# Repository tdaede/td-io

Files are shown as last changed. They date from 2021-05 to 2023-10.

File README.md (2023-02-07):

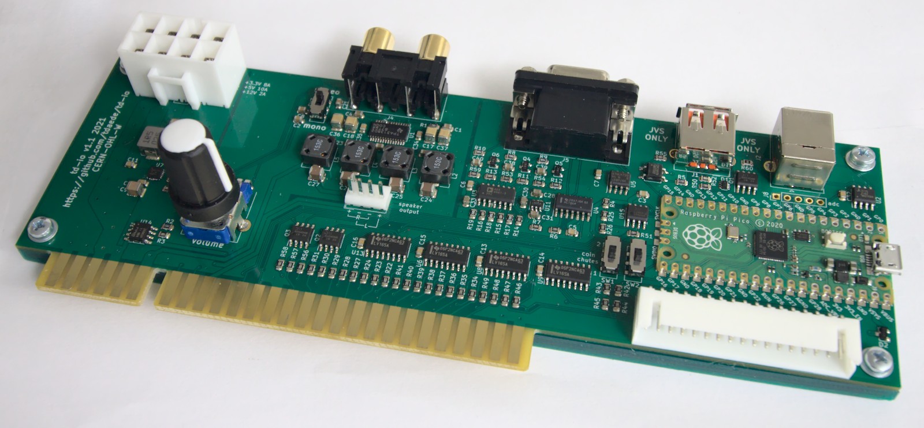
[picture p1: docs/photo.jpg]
td-io


td-io is a JVS I/O board designed to adapt older JAMMA-compatible cabinets to the newer JVS standard, used by modern arcade hardware such as the Naomi and exA. It features a number of independent systems to translate signals, drive cabinet hardware, and power JVS games.

# Features at a glance

* Chainable JVS I/O implementing a 2L12B panel and coin inputs
* JVS to JAMMA video converter compatible with all monitors
* Mono/stereo audio amplifier for driving JAMMA speakers
* JVS power connector providing 3.3V via an on-board converter
* High reliability, low heat generation and all solid state caps
* Upgradeable firmware

# Comparison with other JVS I/O options

| | TD-IO | Capcom I/O | Sega 838 | Exa I/O |
| --- | --- | --- | --- | --- |
| Lag (frames)  | 0 | 1 | 0 | 0 |
| Chaining | ✔ | ❌ | ✔ | ✔ |
| Video | ✔ | ✔ | ✔ | ❌ |
| Audio amp | ✔ | ✔ | ❌ | ❌ |
| 3.3V power | ✔ | ✔ | ❌ | ❌ |
| Amplified stereo | ✔ | ❌ | ❌ | ❌ |

# JVS inputs

The JVS I/O bus connects to the board via USB-style A and B connectors. Daisy chaining is supported. The I/O presents two players, each with a single joystick/lever and six buttons. Joystick and button 1-4 inputs are mapped to the JAMMA edge connector, and buttons 4-6 are mapped to a CPS2-style kick harness connector. Buttons are polled synchronously, ensuring microsecond-level latency.

Service, test, and tilt buttons are also supported. JAMMA's single service button is mapped to JVS player 1's service button.

The board also presents one or two coin slots, toggleable by a DIP switch. The board also features two coin meter drivers and two coin lockout drivers. Coins are locked out when the respective coin count is set to its max value (16383).

# Video

The board maps JVS-level video (0.7Vp-p, AC or DC coupled) to JAMMA levels (0-3V, DC coupled). This is achieved via a DC restore step using the sync signal, followed by a fixed amplification. The DC coupled output allows maximum compatibility with monitors such as the Nanao MS8 and capture devices such as the Splitfire which require it.

In addition, a sync combiner combines negative H/V sync to negative composite sync.

No rate conversion is performed - the monitor must support the same scan rates as the JVS game.

An EDID EEPROM is also attached to the VGA port, to identify as a 31kHz monitor.

# Audio

TD-IO provides a class-D audio amplifier, which can drive both mono and stereo speakers in JAMMA cabinets. For mono cabinets, audio is simply provided via the JAMMA edge. For stereo support, the cabinet's speakers should be connected to the JST NH header provided on the I/O. The pinout of this header is directly compatible with the Egret 2, and adapters can be easily made for other cabinets, such as the Aero.

The stereo/mono switch selects whether to mixdown the L/R channels to mono. It should be set to mono when using a mono cabinet via the JAMMA edge, and stereo when using a cabinet with the stereo header.

The stereo support is not directly compatible with nonstandard Neo Geo style stereo over JAMMA, with a common ground. For these cabinets, either use the TD-IO in mono mode, or rewire the cabinet to connect directly to the stereo header. The left/right negative speaker outputs should not be tied together.

## Aero City stereo adapter

| JST NH H4P-SHF-AA | Molex MLX 50-84-2042 |
| --- | --- |
| 1 | 2 |
| 2 | 3 |
| 3 | 1 |
| 4 | 4 |

# Power

An 8-pin JVS power connector forwards 12V and 5V from the cabinet to the JVS board. In addition, an on-board power supply generates 3.3V at up to 7A from the cabinet's 5V rail for systems that require it, such as Naomi.

The cabinet's 5V power supply must still be adequate to power the 3.3V converter.

The IO's electronics are protected from overvoltage and overcurrent by an automatically resetting protector.

# Firmware Updates

The board features an on-board RP2040 microcontroller, whose firmware can be updated over USB for feature enhancements or compatibility fixes.

To update the firmware, turn off power to the cabinet (if attached). Then, attach a USB cable to the micro USB connector. Hold down the white button on the RP2040 while plugging the USB connector into a PC. The TD-IO will then appear as a flash drive. Copy the firmware file (ending in .uf2) onto the drive. The TD-IO will then disconnect and be ready for use.

# Analog Input

The board features an unpopulated expansion header exposing 3 3.3V level analog inputs, designed for potentiometers for analog joystick or racing games. This feature is experimental and not yet implemented in the firmware.

# Where to buy

The board is not currently for sale, as testing is not yet complete.

# License

CERN-OHL-W

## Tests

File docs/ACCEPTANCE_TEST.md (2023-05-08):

# Programming

Plug the micro-USB port on the edge of td-io into a computer. It will appear as a USB flash drive. Drag and drop the firmware U2F file onto the flash drive. When programming is complete, the drive will disconnect automatically.

Once programmed, the white button must be held when plugging in the USB cable to re-enter programming mode.

# Basic test

1. Power the board via a JAMMA supergun.

2. Measure the pins on the JVS power connector and make sure the +3.3V line measures between 3.27V and 3.39V.

3. Ensure the volume pot turns smoothly and is not loose.

4. Set the switch default positions to 2 coin chutes and mono sound.

# Functionality test

5. Attach a JVS host to the JVS connectors. Ensure that the green LED illuminates once the host initializes JVS.

6. Attach a sound source to the RCA connectors. Ensure that the sound is audible via either the JAMMA connector or via the stereo header.

7. Attach a video source to the VGA connector. Ensure that video appears via the supergun.

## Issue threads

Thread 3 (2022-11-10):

Inductorless class-d amplifier in JAMMA cabinets

prrole, 2022-11-10:
Nice project, and good idea to use the RP2040.

Just a quick note to share some experience with this.  On a JAMMA project I experienced really bad video distortion/interference, when using it in a cabinet.  Long story short - I finally tracked it down to the inductorless class-d audio amplifier I used.  Internally in the cab, speaker and video signals were close on the JAMMA harness, like they usually are, and the PWM-like output of the audio amplifier interfered with the video signals.

tdaede, 2022-11-10:
Indeed, inductorless is usually only usable with very short wires to the speaker. td-io uses LC filters for this reason.

Closed 2023-03-28.

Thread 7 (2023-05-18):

Recommendation for F1-F6 voltage and current?

dangermousehouse, 2023-05-18:
Thank you for adding fuses to the most recent design! Do you have a recommendation for voltage/current on these fuses?

tdaede, 2023-06-15:
The part is indicated in the Digikey field in the schematic: https://www.digikey.com/en/products/detail/bel-fuse-inc/0ZCG0050AF2C/4156100

Older versions use drivers with integrated current limiters, however those became unavailable.

Closed 2023-06-15.

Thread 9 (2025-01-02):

Receiving a reset message should also reset bus speed

prrole, 2025-01-02:
As title says, if a reset is received when operating in 1mbit or 3mbit, the bus speed should probably be set to power-on parameters, 115200.
```
 if ((msg_length - i) >= 2 && message[i] == 0xf0 && message[i+1] == 0xd9) {
                        printf("N: %02x Reset\n", node_num);
                        our_address = 0;
                        gpio_put(PIN_JVS_SENSE_0V, 0);
                        gpio_put(PIN_LED_ENUMERATED, 0);
                        uart_init(uart0, 115200);  // Set to standard JVS speed
```

Grinkers, 2025-02-02:
I think we can do this without causing issue, but I'm curious what caused you to need this?

As far as I'm aware, exa is the only one using a non-default bus speed and all exa games should be automatically be going back to default speed on exit for compatibility.

On any default speed only systems, this reset command won't be able to reach the IO board if it's acting at 1 or 3 mbit. If everybody is on 1 or 3 mbit, the reset command should probably stay at the working bus speed? I think if you're doing system side things, for maximum compatibility across all boards, you could do something like [broadcast default speed](https://github.com/exA-Arcadia/exa-io/blob/exa/JVS-Dash.md#command-0f2h-comm-method-change-commchg) at 1mbit and 3mbit speeds (so all boards get it), then do the resets.

prrole, 2025-02-02:
If a system resets and goes back to default speed, it will not be able to initialize the bus as the IO board(s) are operating in non-default speed.  Changing the speed without having an initialized bus, like knowing how many (if any) boards are present, seems odd, so I propose that the 'reset' command should switch back to 115200 as the cleanest solution.  And yes, the reset command would have to be sent on all speeds - but this is easy to accommodate in a start-up sequence.

My application are the products over at https://irkenlabs.com/

Grinkers, 2025-02-03:
The COMMCHG command is a broadcast command, so it's specifically for times when you don't know how many boards are on the bus, just like reset. So if I understand you want to do

```python
# [broadcast, reset] at 1mbit
[0xff, 0xf0]
# [broadcast, reset] at 3mbit
[0xff, 0xf0]
# [broadcast, reset] at default
[0xff, 0xf0]
```
I don't think this change would cause any compatibility issues with exa systems or td-io based io boards... however if you do the following, we won't need to do any change and you'll already be compatible with everything

```python
# [broadcast, commchg, default] at 1mbit
[0xff, 0xf2, 0x00]
# [broadcast, commchg, default] at 3mbit
[0xff, 0xf2, 0x00]
# [broadcast, reset] at default
[0xff, 0xf0]
```

fwiw, at exa we roughly do
```python
count = 0
for n in 0..0x20 {
  # CMDREV as an ack
  if req([n, 0x11]):
    count++
    continue
  return count
}
```
```python
if count_acks() != 0:
  continue
else:
  setcomm(3m)

if count_acks() != 0:
  continue
else:
  setcomm(default)
  reset()
```

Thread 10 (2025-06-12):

Thermal protection on the SIC437A

BigPBigP, 2025-06-12:
I built a number of these and they are pretty amazing. One issue I have come across is running the TD-IO on a Naomi wipi netdimm setup the SIC437A enters thermal protection after about 30min, dropping the power for a few mili seconds, which is just enough to freeze the system. Upon reading the SIC437A datasheet heatsinking is recommended and once I installed a copper heatsink the problem is resolved. Currently I was unable to find a a heatsink that fits due to the small size of the SIC437A and the proximity of surrounding components. The work around is cutting down a RPi heatsink to 4x4mm (2x2 top squares) or re laying out the area around the SIC437A to allow for a larger heatsink.

BigPBigP, 2025-09-17:
Yes there could be quite a few variables that contribute to this, including ambient temp, psu type and even my choice of solder, flux and technique. It took me ages to debug but a few things since have totally confirmed this. I initially used thermal tape to secure the heatsink and it ran great for 2 months, then it happened again. When I went to work it out I found that the tape bond had gone. Once it was cleaned and heatsink glued it was working great again. So my only addition is use heatsink plaster to secure it as the cut down RPi heatsink has alot of height for the tiny attachment area. Besides this the SIC437A works great and once sinked it works great. My idea is just a minor re-layout surrounding the SIC437A to get a standard small heatsink to fit, but I have not gotten to it yet.

tdaede, 2025-09-17:
I can probably put enough clearance on future versions for something like this: https://www.adafruit.com/product/1493
Unfortunately moving the parts away reduces performance. Another option is forced air - even a small amount can make a huge difference.

BigPBigP, 2025-09-18:
That looks great. It only appears to be an issue with Naomi and Naomi 2 (which are really voltage sensitive) and only when running a net dimm which gets really close to the 7A (?) max. The main reason I have not gotten to it is exactly the reason you mentioned, I couldn't find the time to work out how far I could move stuff to get the performance / space balance right. I had also considered designing a 3d printable case for the TD-IO with the capacity to fan it. Pity we have day jobs.

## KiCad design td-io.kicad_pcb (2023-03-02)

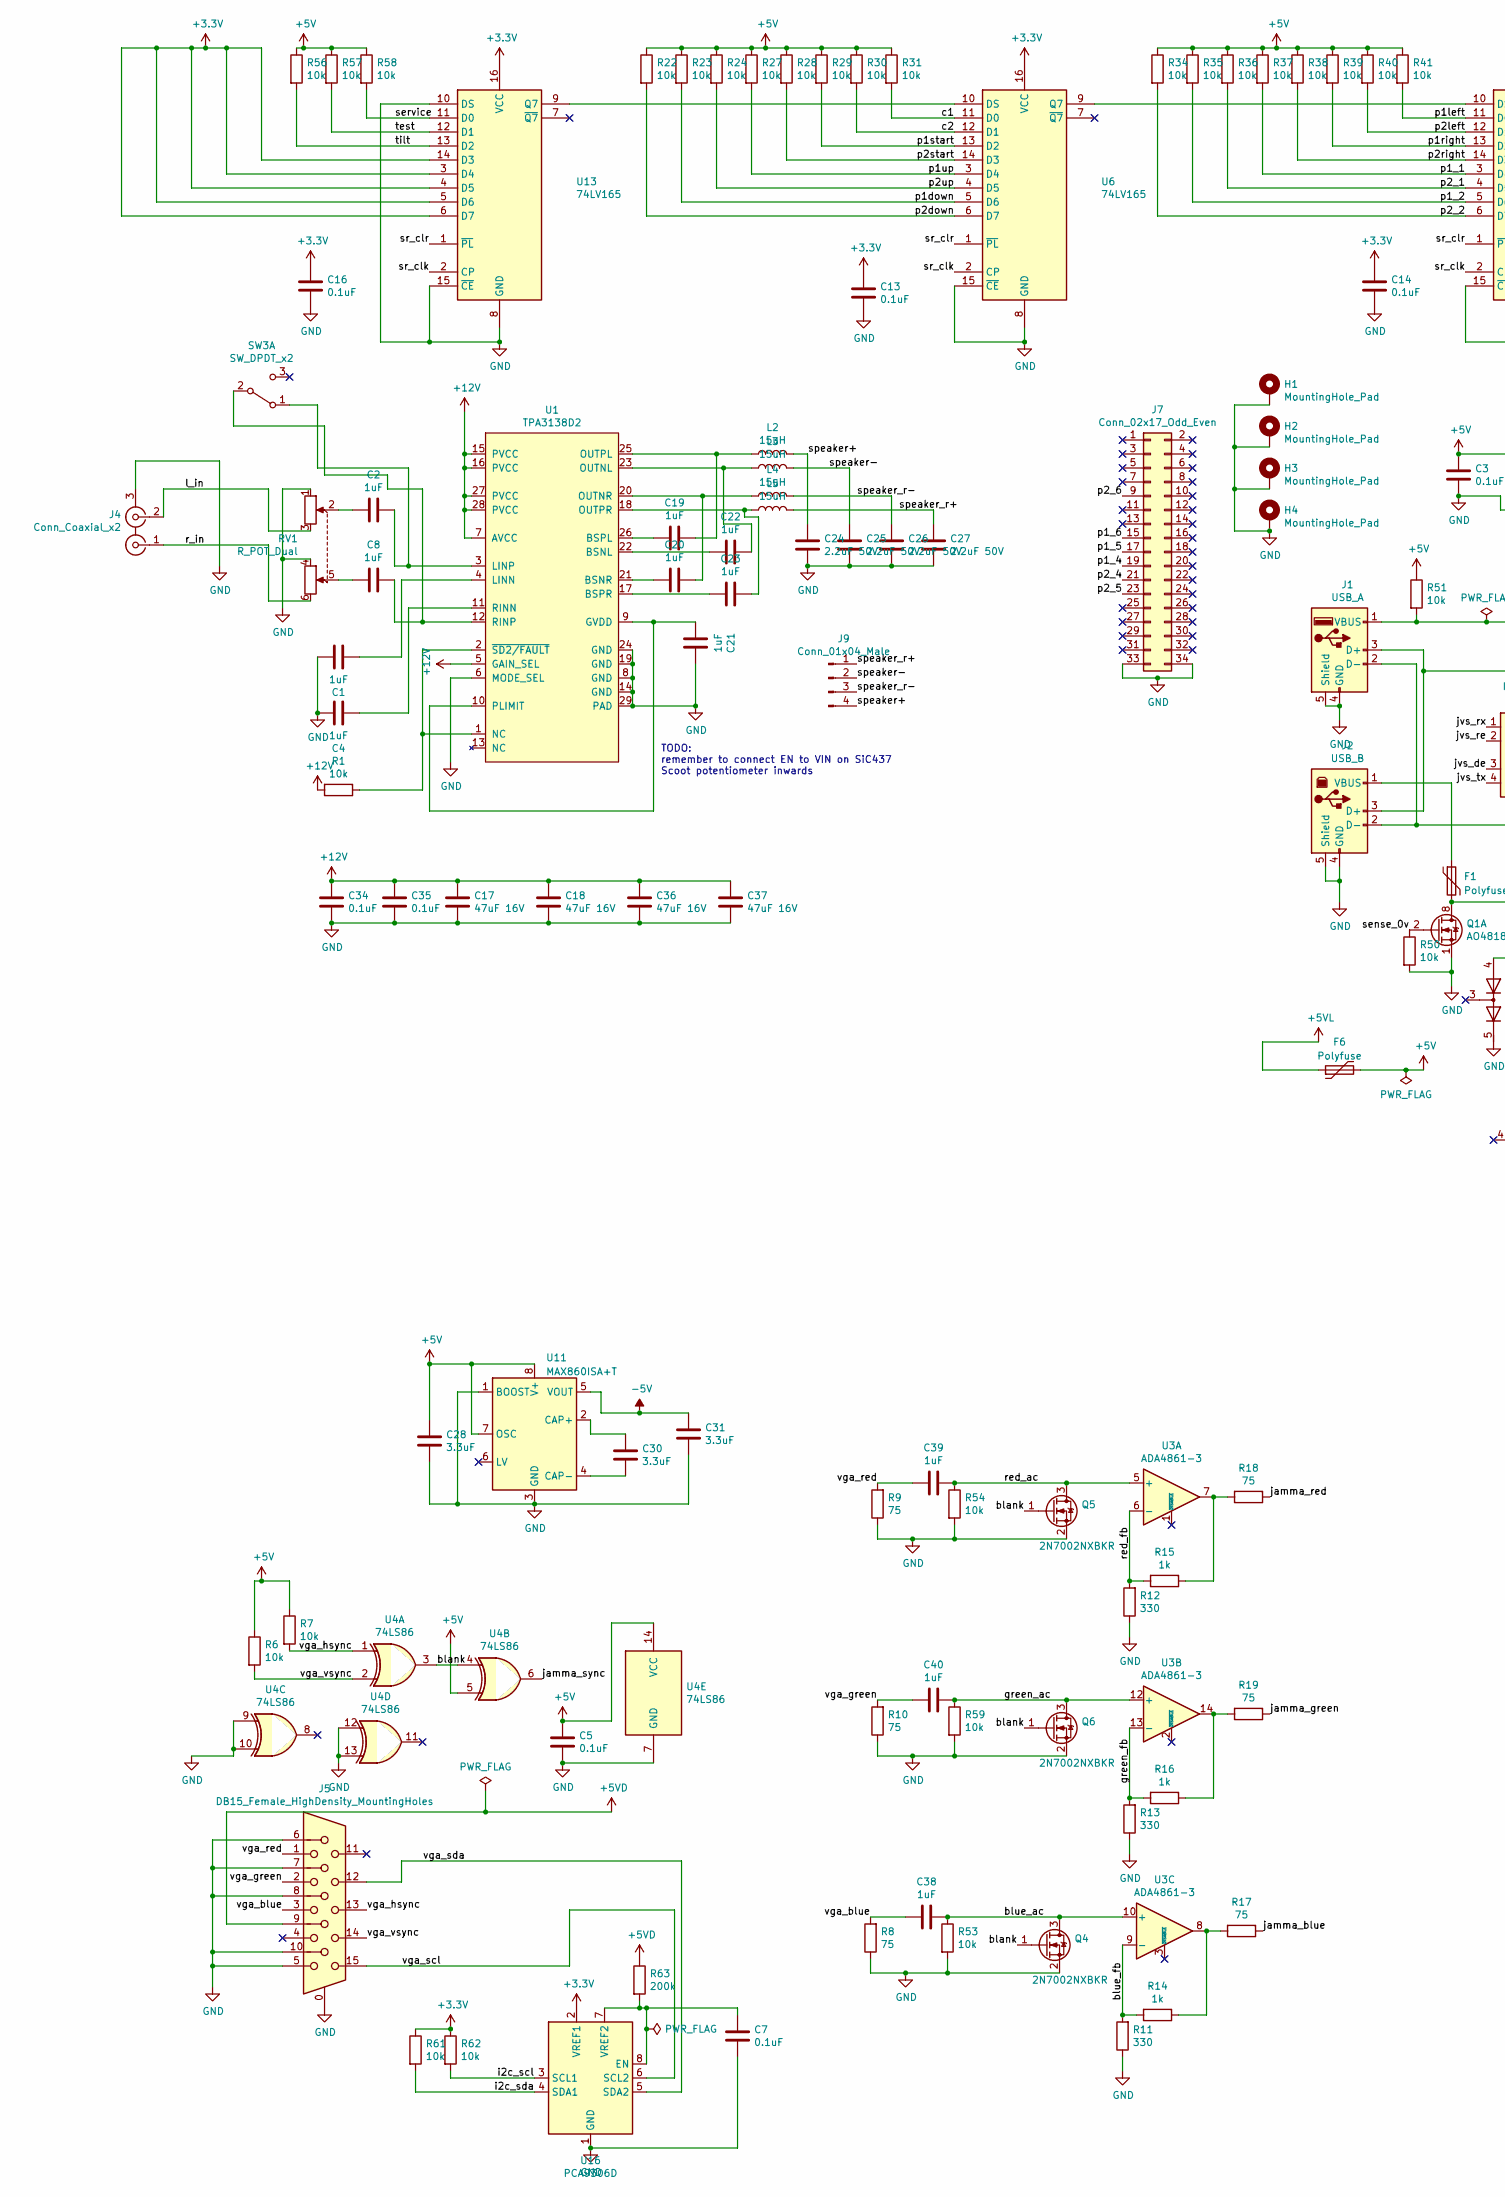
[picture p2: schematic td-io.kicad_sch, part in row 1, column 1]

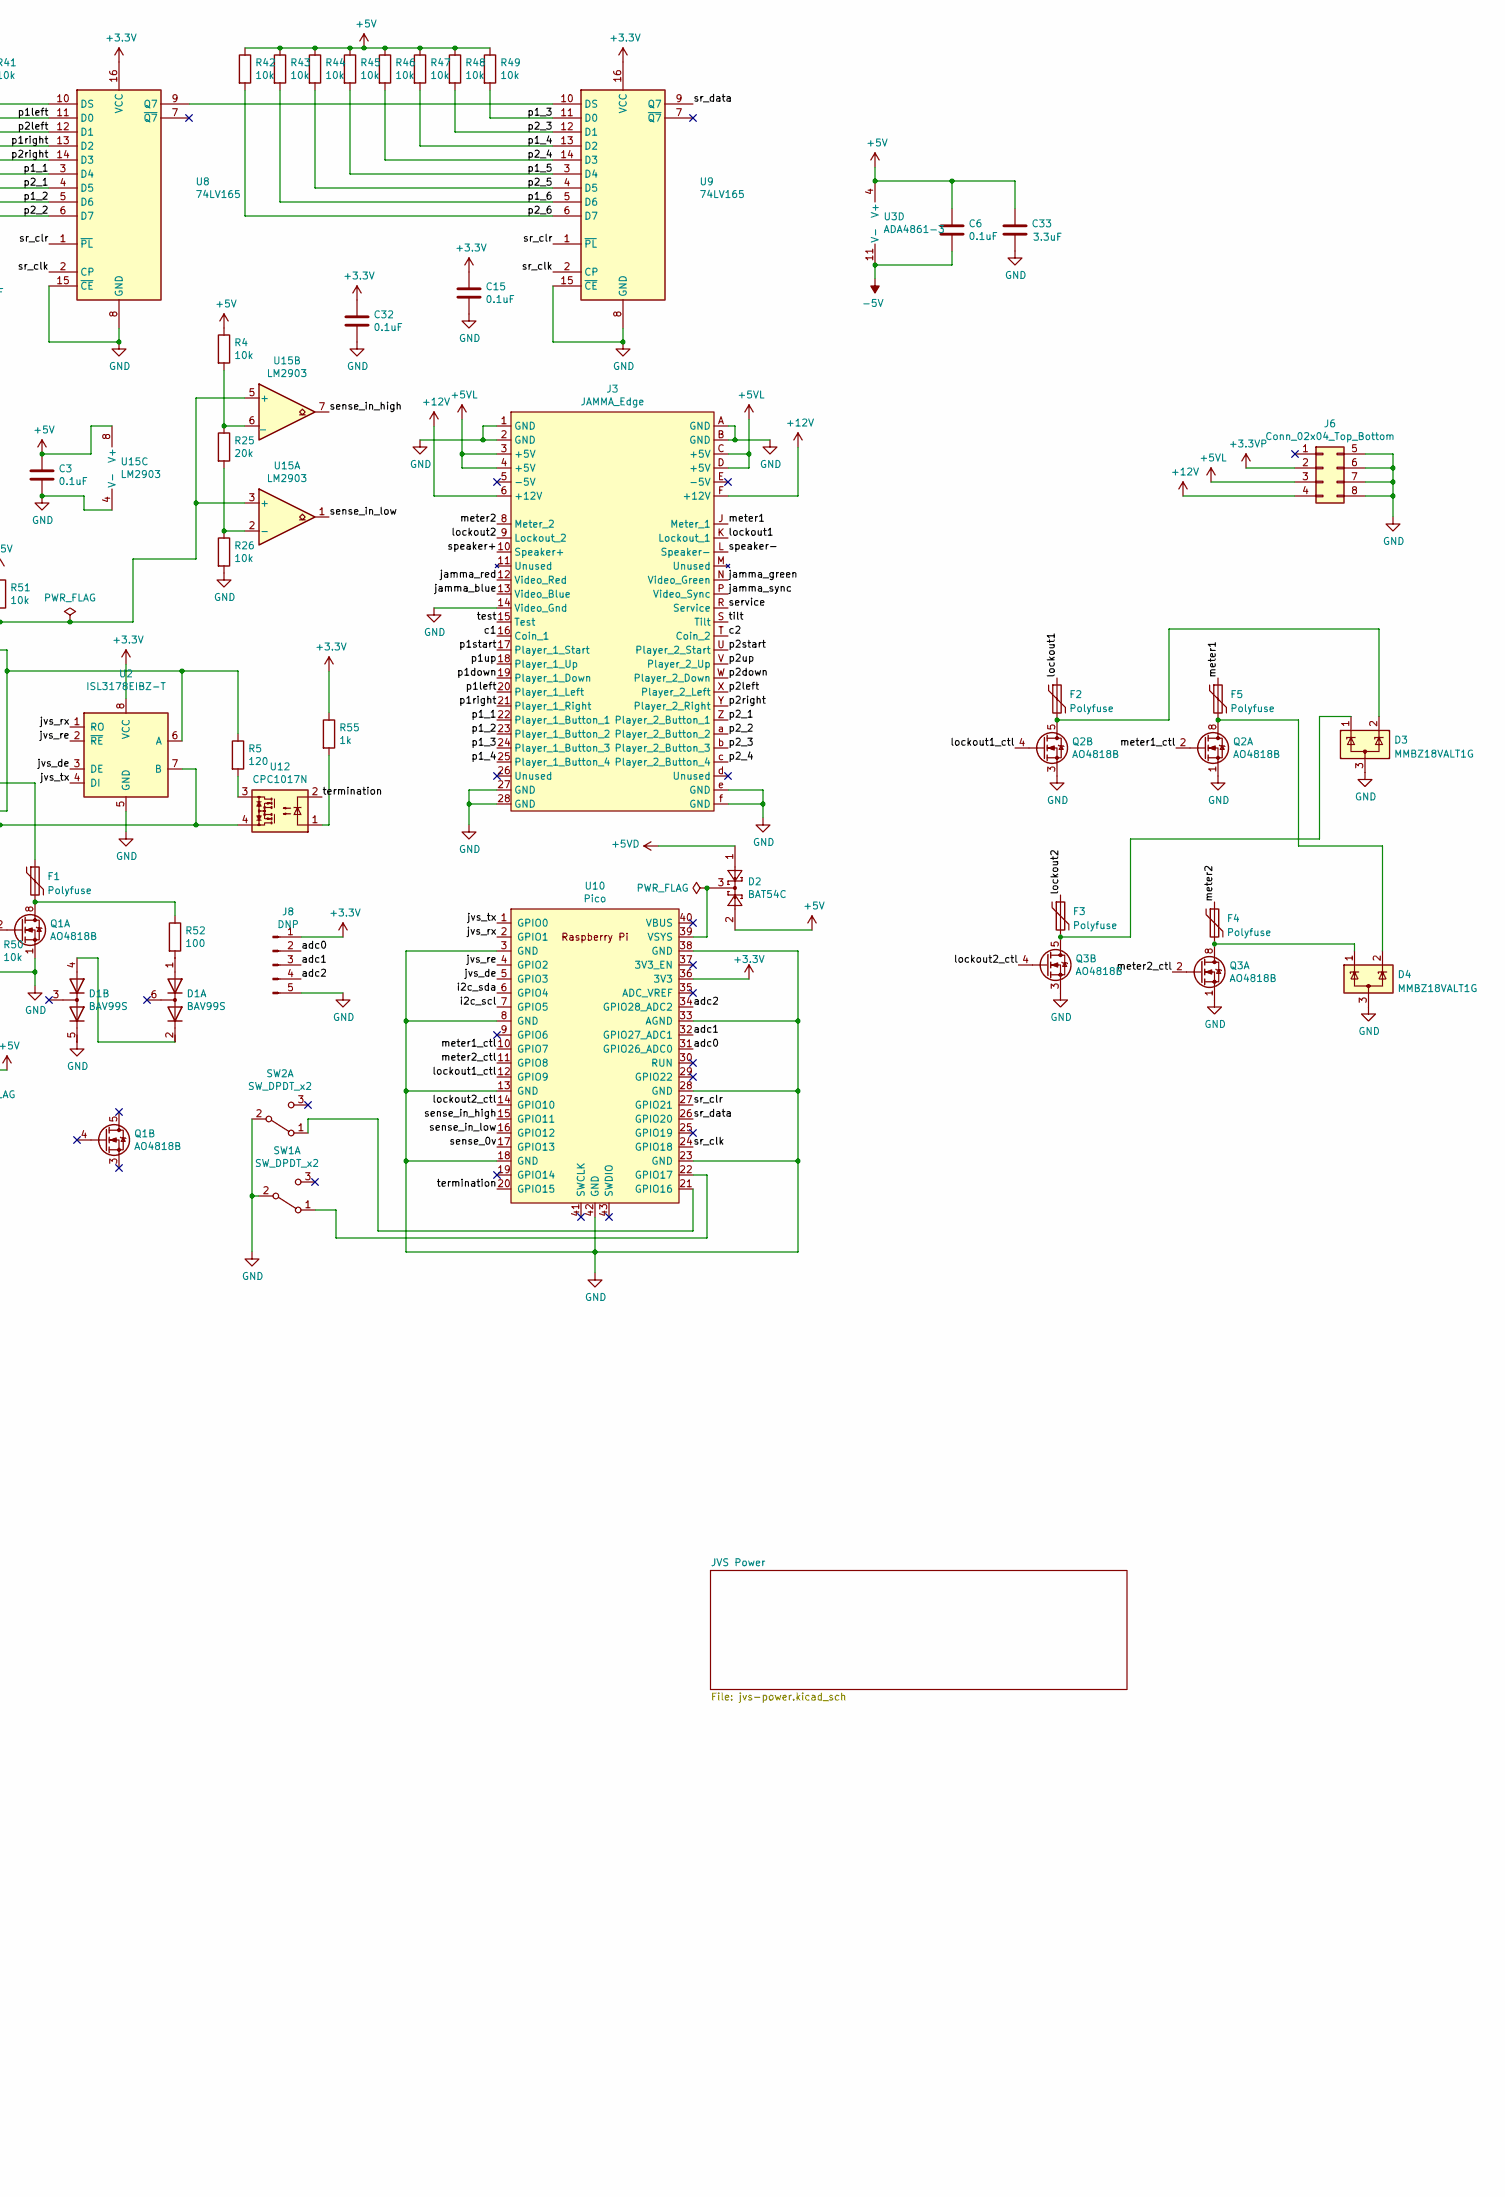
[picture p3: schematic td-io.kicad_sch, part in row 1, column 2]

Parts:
C1, C2, C4, C8, C19, C20, C21, C22, C23, C38, C39, C40: 1uF; C_0805_2012Metric; Digikey 1276-2926-1-ND
C3, C5, C6, C7, C13, C14, C15, C16, C32, C34, C35: 0.1uF; C_0805_2012Metric; Digikey 1276-2444-1-ND
C17, C18, C36, C37: 47uF 16V; C_1210_3225Metric; Digikey 490-16309-1-ND
C24, C25, C26, C27: 2.2uF 50V; C_1210_3225Metric; Digikey 1276-2884-1-ND
C28, C30, C31, C33: 3.3uF; C_0805_2012Metric; Digikey 1276-6461-1-ND
D1: BAV99S; SOT-363_SC-70-6; Digikey 1727-4042-1-ND
D2: BAT54C; SOT-23; Digikey BAT54CFSCT-ND
D3, D4: MMBZ18VALT1G; SOT-23; Digikey MMBZ18VALT1GOSTR-ND
F1, F2, F3, F4, F5, F6: Polyfuse; R_1812_4532Metric; Digikey 507-1762-1-ND
H1, H2, H3, H4: MountingHole_Pad; MountingHole_3.2mm_M3_Pad_Via
J1: USB_A; USB_A_Molex_67643_Horizontal; Digikey SAM10870-ND
J2: USB_B; USB_B_OST_USB-B1HSxx_Horizontal; Digikey SAM10873-ND
J3: JAMMA_Edge; JAMMA
J4: Conn_Coaxial_x2; PJRAN2X1U01AUX; Digikey SC2534-ND
J5: DB15_Female_HighDensity_MountingHoles; DSUB-15-HD_Female_Horizontal_P2.29x2.5mm_EdgePinOffset8.35m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; Digikey Z13226-ND
J6: Conn_02x04_Top_Bottom; B08P-VL; Digikey 455-2365-ND
J7: Conn_02x17_Odd_Even; DF1BZ-34DP-2.5DS; Digikey H11039-ND
J8: DNP; PinHeader_1x05_P2.54mm_Vertical
J9: Conn_01x04_Male; JST_SH_B4B-NH-A_1x04_P2.50mm_Vertical; Digikey 455-4179-ND
L2, L3, L4, L5: 15uH; L_7.3x7.3_H4.5; Digikey 811-3582-1-ND
Q1, Q2, Q3: AO4818B; SOIC-8_3.9x4.9mm_P1.27mm; Digikey 785-1059-1-ND
Q4, Q5, Q6: 2N7002NXBKR; SOT-23; Digikey 1727-8642-1-ND
R1, R4, R6, R7, R22, R23, R24, R26, R27, R28, R29, R30, R31, R34, R35, R36, R37, R38, R39, R40, R41, R42, R43, R44, R45, R46, R47, R48, R49, R50, R51, R53, R54, R56, R57, R58, R59, R61, R62: 10k; R_0805_2012Metric; Digikey 311-10.0KCRCT-ND
R5: 120; R_0805_2012Metric; Digikey 13-RT0805FRE07120RLCT-ND
R8, R9, R10, R17, R18, R19: 75; R_0805_2012Metric; Digikey 311-75.0CRCT-ND
R11, R12, R13: 330; R_0805_2012Metric; Digikey 311-330CRCT-ND
R14, R15, R16, R55: 1k; R_0805_2012Metric; Digikey 311-1.00KCRCT-ND
R25: 20k; R_0805_2012Metric; Digikey 311-20.0KCRCT-ND
R52: 100; R_0805_2012Metric; Digikey 311-100CRCT-ND
R63: 200k; R_0805_2012Metric; Digikey 311-200KCRCT-ND
RV1: R_POT_Dual; PTV112-4420A-A503; Digikey PTV112-4420A-A503-ND
SW1, SW2, SW3: SW_DPDT_x2; SW_DPDT_CK_JS202011JCQN; Digikey CKN10723CT-ND
U1: TPA3138D2; HTSSOP-28-1EP_4.4x9.7mm_P0.65mm_tpa3138_ThermalVias; Digikey 296-50219-ND
U2: ISL3178EIBZ-T; SOIC-8_3.9x4.9mm_P1.27mm; Digikey 20-ISL3178EIBZ-TCT-ND
U3: ADA4861-3; SOIC-14_3.9x8.7mm_P1.27mm; Digikey ADA4861-3YRZ-RL7CT-ND
U4: 74LS86; SOIC-14_3.9x8.7mm_P1.27mm; Digikey 296-8201-1-ND
U6, U8, U9, U13: 74LV165; SOIC-16_3.9x9.9mm_P1.27mm; Digikey 296-SN74LV165ADRG3CT-ND
U10: Pico; RPi_Pico_SMD; Digikey 2648-SC0915CT-ND
U11: MAX860ISA+T; SOIC-8_3.9x4.9mm_P1.27mm; Digikey MAX860ISA+TCT-ND
U12: CPC1017N; SOP-4_3.8x4.1mm_P2.54mm; Digikey CLA153-ND
U15: LM2903; SOIC-8_3.9x4.9mm_P1.27mm; Digikey 296-27463-1-ND
U16: PCA9306D; SO-8_3.9x4.9mm_P1.27mm; Digikey 568-4215-1-ND

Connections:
+3.3V: C13.1, C14.1, C15.1, C16.1, C32.1, J8.1, R55.1, R61.1, R62.1, U2.8 (VCC), U6.16 (VCC), U8.16 (VCC), U9.16 (VCC), U10.36 (3V3), U13.3 (D4), U13.4 (D5), U13.5 (D6), U13.6 (D7), U13.14 (D3), U13.16 (VCC), U16.2 (VREF1)
+3.3VP: J6.2; also elsewhere on the board
+5V: C3.1, C5.1, C6.1, C28.1, C33.1, D2.2, F6.2, R4.1, R6.1, R7.1, R22.1, R23.1, R24.1, R27.1, R28.1, R29.1, R30.1, R31.1, R34.1, R35.1, R36.1, R37.1, R38.1, R39.1, R40.1, R41.1, R42.1, R43.1, R44.1, R45.1, R46.1, R47.1, R48.1, R49.1, R51.1, R56.1, R57.1, R58.1, U3.4 (V+), U4.5, U4.14 (VCC), U11.7 (OSC), U11.8 (V+), U15.8 (V+)
+5VD: D2.1, J5.9, R63.1
+5VL: F6.1, J3.3 (+5V), J3.4 (+5V), J3.C (+5V), J3.D (+5V), J6.3; also elsewhere on the board
+12V: C17.1, C18.1, C34.1, C35.1, C36.1, C37.1, J3.6 (+12V), J3.F (+12V), J6.4, R1.2, U1.5 (GAIN_SEL), U1.7 (AVCC), U1.15 (PVCC), U1.16 (PVCC), U1.27 (PVCC), U1.28 (PVCC)
-5V: C6.2, C31.1, U3.11 (V-), U11.5 (VOUT)
/adc0: J8.2, U10.31 (GPIO26_ADC0)
/adc1: J8.3, U10.32 (GPIO27_ADC1)
/adc2: J8.4, U10.34 (GPIO28_ADC2)
/blank: Q4.1 (G), Q5.1 (G), Q6.1 (G), U4.3, U4.4
/blue_ac: C38.1, Q4.3 (D), R53.1, U3.10 (+)
/blue_fb: R11.2, R14.2, U3.9 (-)
/c1: J3.16 (Coin_1), R31.2, U6.11 (D0)
/c2: J3.T (Coin_2), R30.2, U6.12 (D1)
/green_ac: C40.1, Q6.3 (D), R59.1, U3.12 (+)
/green_fb: R13.2, R16.2, U3.13 (-)
/i2c_scl: R62.2, U10.7 (GPIO5), U16.3 (SCL1)
/i2c_sda: R61.2, U10.6 (GPIO4), U16.4 (SDA1)
/jamma_blue: J3.13 (Video_Blue), R17.1
/jamma_green: J3.N (Video_Green), R19.1
/jamma_red: J3.12 (Video_Red), R18.1
/jamma_sync: J3.P (Video_Sync), U4.6
/jvs_de: U2.3 (DE), U10.5 (GPIO3)
/jvs_re: U2.2 (~RE), U10.4 (GPIO2)
/jvs_rx: U2.1 (RO), U10.2 (GPIO1)
/jvs_tx: U2.4 (DI), U10.1 (GPIO0)
/l_in: J4.2 (IN2), RV1.3
/lockout1: F2.1, J3.K (Lockout_1)
/lockout1_ctl: Q2.4 (G2), U10.12 (GPIO9)
/lockout2: F3.1, J3.9 (Lockout_2)
/lockout2_ctl: Q3.4 (G2), U10.14 (GPIO10)
/meter1: F5.1, J3.J (Meter_1)
/meter1_ctl: Q2.2 (G1), U10.10 (GPIO7)
/meter2: F4.1, J3.8 (Meter_2)
/meter2_ctl: Q3.2 (G1), U10.11 (GPIO8)
/p1_1: J3.22 (Player_1_Button_1), R37.2, U8.3 (D4)
/p1_2: J3.23 (Player_1_Button_2), R35.2, U8.5 (D6)
/p1_3: J3.24 (Player_1_Button_3), R49.2, U9.11 (D0)
/p1_4: J3.25 (Player_1_Button_4), J7.19, R47.2, U9.13 (D2)
/p1_5: J7.17, R45.2, U9.3 (D4)
/p1_6: J7.15, R43.2, U9.5 (D6)
/p1down: J3.19 (Player_1_Down), R23.2, U6.5 (D6)
/p1left: J3.20 (Player_1_Left), R41.2, U8.11 (D0)
/p1right: J3.21 (Player_1_Right), R39.2, U8.13 (D2)
/p1start: J3.17 (Player_1_Start), R29.2, U6.13 (D2)
/p1up: J3.18 (Player_1_Up), R27.2, U6.3 (D4)
/p2_1: J3.Z (Player_2_Button_1), R36.2, U8.4 (D5)
/p2_2: J3.a (Player_2_Button_2), R34.2, U8.6 (D7)
/p2_3: J3.b (Player_2_Button_3), R48.2, U9.12 (D1)
/p2_4: J3.c (Player_2_Button_4), J7.21, R46.2, U9.14 (D3)
/p2_5: J7.23, R44.2, U9.4 (D5)
/p2_6: J7.9, R42.2, U9.6 (D7)
/p2down: J3.W (Player_2_Down), R22.2, U6.6 (D7)
/p2left: J3.X (Player_2_Left), R40.2, U8.12 (D1)
/p2right: J3.Y (Player_2_Right), R38.2, U8.14 (D3)
/p2start: J3.U (Player_2_Start), R28.2, U6.14 (D3)
/p2up: J3.V (Player_2_Up), R24.2, U6.4 (D5)
/r_in: J4.1 (IN1), RV1.6
/red_ac: C39.1, Q5.3 (D), R54.1, U3.5 (+)
/red_fb: R12.2, R15.2, U3.6 (-)
/sense_0v: Q1.2 (G1), R50.1, U10.17 (GPIO13)
/sense_in_high: U10.15 (GPIO11), U15.7
/sense_in_low: U10.16 (GPIO12), U15.1
/service: J3.R (Service), R58.2, U13.11 (D0)
/speaker+: C24.1, J3.10 (Speaker+), J9.4, L2.2
/speaker-: C25.1, J3.L (Speaker-), J9.2, L3.2
/speaker_r+: C27.1, J9.1, L5.2
/speaker_r-: C26.1, J9.3, L4.2
/sr_clk: U6.2 (CP), U8.2 (CP), U9.2 (CP), U10.24 (GPIO18), U13.2 (CP)
/sr_clr: U6.1 (~PL), U8.1 (~PL), U9.1 (~PL), U10.27 (GPIO21), U13.1 (~PL)
/sr_data: U9.9 (Q7), U10.26 (GPIO20)
/termination: U10.20 (GPIO15), U12.2
/test: J3.15 (Test), R57.2, U13.12 (D1)
/tilt: J3.S (Tilt), R56.2, U13.13 (D2)
/vga_blue: C38.2, J5.3, R8.2
/vga_green: C40.2, J5.2, R10.2
/vga_hsync: J5.13, R7.2, U4.1
/vga_red: C39.2, J5.1, R9.2
/vga_scl: J5.15, U16.6 (SCL2)
/vga_sda: J5.12, U16.5 (SDA2)
/vga_vsync: J5.14, R6.2, U4.2
GND: C1.1, C3.2, C4.1, C5.2, C7.2, C13.2, C14.2, C15.2, C16.2, C17.2, C18.2, C21.1, C24.2, C25.2, C26.2, C27.2, C28.2, C31.2, C32.2, C33.2, C34.2, C35.2, C36.2, C37.2, D1.5 (K4), D3.3 (A), D4.3 (A), H1.1, H2.1, H3.1, H4.1, J1.4 (GND), J1.5 (Shield), J2.4 (GND), J2.5 (Shield), J3.1 (GND), J3.2 (GND), J3.14 (Video_Gnd), J3.27 (GND), J3.28 (GND), J3.A (GND), J3.B (GND), J3.e (GND), J3.f (GND), J4.3 (EXT), J5.0, J5.5, J5.6, J5.7, J5.8, J5.10, J6.5, J6.6, J6.7, J6.8, J7.33, J7.34, J8.5, Q1.1 (S1), Q2.1 (S1), Q2.3 (S2), Q3.1 (S1), Q3.3 (S2), Q4.2 (S), Q5.2 (S), Q6.2 (S), R8.1, R9.1, R10.1, R11.1, R12.1, R13.1, R26.2, R50.2, R53.2, R54.2, R59.2, RV1.1, RV1.4, SW1.2 (B), SW2.2 (B), U1.6 (MODE_SEL), U1.8 (GND), U1.14 (GND), U1.19 (GND), U1.24 (GND), U1.29 (PAD), U2.5 (GND), U4.7 (GND), U4.9, U4.10, U4.12, U4.13, U6.8 (GND), U6.15 (~CE), U8.8 (GND), U8.15 (~CE), U9.8 (GND), U9.15 (~CE), U10.3 (GND), U10.8 (GND), U10.13 (GND), U10.18 (GND), U10.23 (GND), U10.28 (GND), U10.33 (AGND), U10.38 (GND), U10.42 (GND), U11.1 (BOOST), U11.3 (GND), U13.8 (GND), U13.10 (DS), U13.15 (~CE), U15.4 (V-), U16.1 (GND); also elsewhere on the board
unnamed: C1.2, U1.4 (LINN)
unnamed: C2.1, SW3.1 (A), U1.3 (LINP)
unnamed: C2.2, RV1.2
unnamed: C4.2, U1.11 (RINN)
unnamed: C7.1, R63.2, U16.7 (VREF2), U16.8 (EN)
unnamed: C8.1, SW3.2 (B), U1.12 (RINP)
unnamed: C8.2, RV1.5
unnamed: C19.1, L2.1, U1.25 (OUTPL)
unnamed: C19.2, U1.26 (BSPL)
unnamed: C20.1, L4.1, U1.20 (OUTNR)
unnamed: C20.2, U1.21 (BSNR)
unnamed: C21.2, U1.9 (GVDD), U1.10 (PLIMIT)
unnamed: C22.1, L3.1, U1.23 (OUTNL)
unnamed: C22.2, U1.22 (BSNL)
unnamed: C23.1, L5.1, U1.18 (OUTPR)
unnamed: C23.2, U1.17 (BSPR)
unnamed: C30.1, U11.2 (CAP+)
unnamed: C30.2, U11.4 (CAP-)
unnamed: D1.1 (A1), R52.2
unnamed: D1.2 (K2), D1.4 (A3)
unnamed: D2.3, U10.39 (VSYS)
unnamed: D3.1 (K), F3.2, Q3.5 (D2), Q3.6 (D2)
unnamed: D3.2 (K), F2.2, Q2.5 (D2), Q2.6 (D2)
unnamed: D4.1 (K), F4.2, Q3.7 (D1), Q3.8 (D1)
unnamed: D4.2 (K), F5.2, Q2.7 (D1), Q2.8 (D1)
unnamed: F1.1, J2.1 (VBUS)
unnamed: F1.2, Q1.7 (D1), Q1.8 (D1), R52.1
unnamed: J1.1 (VBUS), R51.2, U15.3 (+), U15.5 (+)
unnamed: J1.2 (D-), J2.2 (D-), U2.7 (B), U12.4
unnamed: J1.3 (D+), J2.3 (D+), R5.1, U2.6 (A)
unnamed: R1.1, U1.1 (NC), U1.2 (~SD2/FAULT)
unnamed: R5.2, U12.3
unnamed: R14.1, R17.2, U3.8
unnamed: R15.1, R18.2, U3.7
unnamed: R16.1, R19.2, U3.14
unnamed: R4.2, R25.1, U15.6 (_)
unnamed: R25.2, R26.1, U15.2 (-)
unnamed: R55.2, U12.1
unnamed: SW1.1 (A), U10.22 (GPIO17)
unnamed: SW2.1 (A), U10.21 (GPIO16)
unnamed: U6.9 (Q7), U8.10 (DS)
unnamed: U8.9 (Q7), U9.10 (DS)
unnamed: U6.10 (DS), U13.9 (Q7)

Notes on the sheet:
TODO: remember to connect EN to VIN on SiC437 Scoot potentiometer inwards

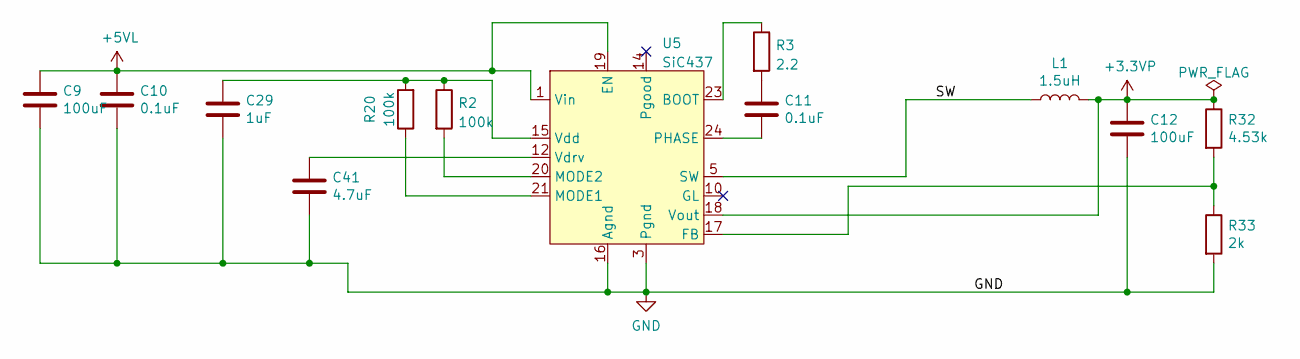
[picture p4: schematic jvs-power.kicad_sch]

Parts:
C9, C12: 100uF; C_1210_3225Metric; Digikey 1276-1092-1-ND
C10, C11: 0.1uF; C_0805_2012Metric; Digikey 1276-2444-1-ND
C29: 1uF; C_0805_2012Metric; Digikey 311-1365-1-ND
C41: 4.7uF; C_0805_2012Metric; Digikey 1276-1259-1-ND
L1: 1.5uH; L_Bourns_SRP7028A_7.3x6.6mm; Digikey SRP7050TA-1R5MCT-ND
R2, R20: 100k; R_0805_2012Metric; Digikey 311-100KCRCT-ND
R3: 2.2; R_0805_2012Metric; Digikey 311-2.2ARCT-ND
R32: 4.53k; R_0805_2012Metric
R33: 2k; R_0805_2012Metric
U5: SiC437; Vishay_PowerPAK_MLP44-24L; Digikey SIC437AED-T1-GE3CT-ND

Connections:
+3.3VP: C12.1, L1.2, R32.1, U5.18 (Vout); also elsewhere on the board
+5VL: C9.1, C10.1, U5.1 (Vin), U5.2 (Vin), U5.19 (EN), U5.22 (Vin), U5.26 (Vin); also elsewhere on the board
/JVS Power/SW: L1.1, U5.5 (SW), U5.6 (SW), U5.7 (SW), U5.8 (SW), U5.9 (SW)
GND: C9.2, C10.2, C12.2, C29.2, C41.2, R33.2, U5.3 (Pgnd), U5.4 (Pgnd), U5.13 (Pgnd), U5.16 (Agnd), U5.25 (Agnd), U5.27 (Pgnd); also elsewhere on the board
unnamed: C11.1, R3.2
unnamed: C11.2, U5.24 (PHASE)
unnamed: C29.1, R2.1, R20.2, U5.15 (Vdd)
unnamed: C41.1, U5.12 (Vdrv)
unnamed: R2.2, U5.20 (MODE2)
unnamed: R3.1, U5.23 (BOOT)
unnamed: R20.1, U5.21 (MODE1)
unnamed: R32.2, R33.1, U5.17 (FB)

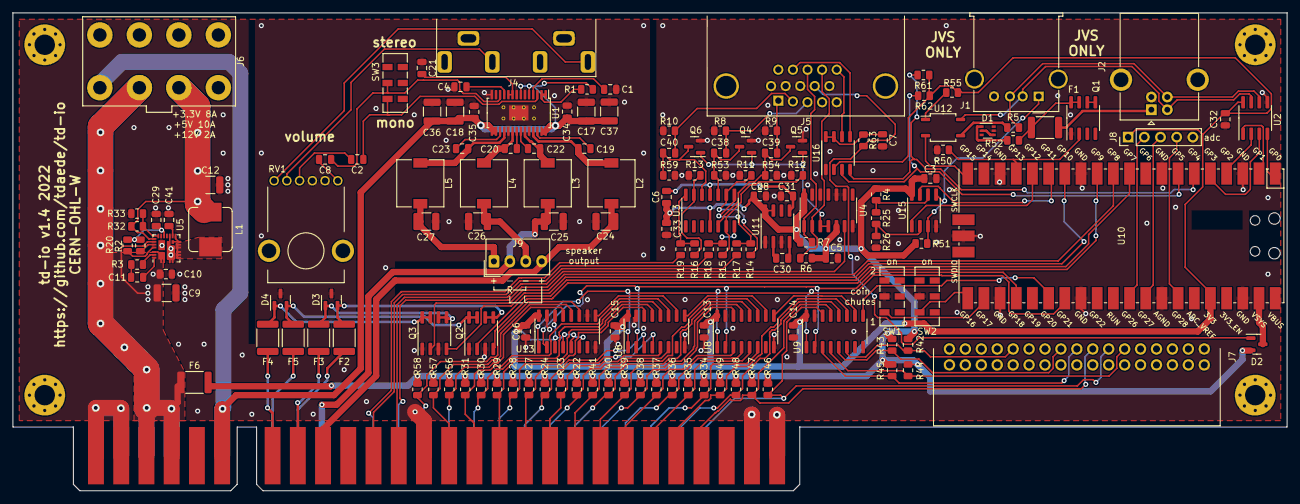
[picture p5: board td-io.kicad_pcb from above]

Board: 2 copper layers, 200.0 x 75.0 mm, 154 parts (0 on the bottom side), 135 nets.

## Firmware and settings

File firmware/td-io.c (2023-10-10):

#include <stdio.h>
#include "pico/stdlib.h"
#include "hardware/adc.h"
#include "edid.h"
#include <string.h>

const uint PIN_JVS_RE = 2;
const uint PIN_JVS_DE = 3;

const uint PIN_JVS_SENSE_2_5V = 14;
const uint PIN_JVS_SENSE_0V = 13;

const uint PIN_JVS_TERMINATION = 15;
const uint PIN_JVS_SENSE_IN_HIGH = 11;
const uint PIN_JVS_SENSE_IN_LOW = 12;

const uint PIN_SR_DATA = 20;
const uint PIN_SR_CLK = 18;
const uint PIN_SR_SH = 21;

const uint PIN_METER1 = 7;
const uint PIN_METER2 = 8;
const uint PIN_LOCKOUT1 = 10;
const uint PIN_LOCKOUT2 = 9;

const uint PIN_LED_ENUMERATED = PICO_DEFAULT_LED_PIN;
const uint PIN_DIP1 = 17;
const uint PIN_DIP2 = 16;

const uint16_t JVS_TERMINATION_THRESHOLD = (uint16_t)(3.75/2.0/3.3*4096);
const uint16_t JVS_0V_THRESHOLD = (uint16_t)(1.25/2.0/3.3*4096);

const uint8_t JVS_STATUS_GOOD = 1;
const uint8_t JVS_STATUS_UNKNOWN_COMMAND = 2;
const uint8_t JVS_STATUS_CHECKSUM_ERROR = 3;
const uint8_t JVS_STATUS_OVERFLOW = 4;

const uint8_t JVS_REPORT_GOOD = 1;
const uint8_t JVS_REPORT_PARAMETER_INVALID = 3;

const uint8_t JVS_MAX_LEN = 253; // minus two for status and checksum
#define JVS_OUTPUT_BUF_LEN 512 // a few bytes to spare for easier overflow checking

// global state
uint8_t our_address = 0;
uint64_t last_process_coin = 0;
// signed for underflow checks
int16_t coin_count_p1 = 0;
int16_t coin_count_p2 = 0;
uint8_t prev_coin_p1 = 0;
uint8_t prev_coin_p2 = 0;
// current JVS comm method
uint8_t jvs_comm_method = 0;

/* Coins are polled between 12ms and 20ms as a min and max time. This value was picked to guarantee
 * a pulse of at least 120ms. The lowest rated coin meters are 10 counts/second. In the case of a
 * coin jam, the maximum pulse will be 200ms. */
const uint8_t METER_TIMEOUT = 11;
uint8_t meter_timeout_p1 = 0;
uint8_t meter_timeout_p2 = 0;

#define SR_P1_3 7
#define SR_P2_3 6
#define SR_P1_4 5
#define SR_P2_4 4
#define SR_P1_5 3
#define SR_P2_5 2
#define SR_P1_6 1
#define SR_P2_6 0
#define SR_P1_LEFT 15
#define SR_P2_LEFT 14
#define SR_P1_RIGHT 13
#define SR_P2_RIGHT 12
#define SR_P1_1 11
#define SR_P2_1 10
#define SR_P1_2 9
#define SR_P2_2 8
#define SR_C1 23
#define SR_C2 22
#define SR_P1_START 21
#define SR_P2_START 20
#define SR_P1_UP 19
#define SR_P2_UP 18
#define SR_P1_DOWN 17
#define SR_P2_DOWN 16
#define SR_SERVICE 31
#define SR_TEST 30
#define SR_TILT 29

const uint8_t JVS_COMM_VER = 0x20;
const char id_str[] = "TD;TD-IO;v1.3;https://github.com/tdaede/td-io";
const char JVS_COMM_SUPPORT = 0x07;
const uint JVS_COMM_SPEEDS[3] = { 115200, 1000000, 3000000 };

const uint8_t input_desc_1coin[] = {
    0x01, 2, 12, 0,
    0x02, 1, 0, 0,
    0x00
};

const uint8_t input_desc_2coin[] = {
    0x01, 2, 12, 0,
    0x02, 2, 0, 0,
    0x00
};

void jvs_sync() {
    uart_putc(uart0, 0xe0);
}

uint8_t jvs_getc() {
    uint8_t c = uart_getc(uart0);
    if (c == 0xd0) {
        c = uart_getc(uart0);
        return c + 1;
    } else {
        return c;
    }
}

void jvs_putc(uint8_t c) {
    if (c == 0xe0) {
        uart_putc(uart0, 0xd0);
        uart_putc(uart0, 0xdf);
    } else if (c == 0xd0) {
        uart_putc(uart0, 0xd0);
        uart_putc(uart0, 0xcf);
    } else {
        uart_putc(uart0, c);
    }
}

void start_transmit() {
    gpio_put(PIN_JVS_RE, 1); // disable receive
    if (jvs_comm_method == 0) {
        // un-upgraded jvs needs at least 100us here
        busy_wait_us_32(200);    // 200us min for exa compat
    }
    gpio_put(PIN_JVS_DE, 1); // enable transmitter
}

void stop_transmit() {
    uart_tx_wait_blocking(uart0);
    gpio_put(PIN_JVS_DE, 0); // disable transmitter
    gpio_put(PIN_JVS_RE, 0); // enable receiver
}

void send_message(uint8_t status, uint8_t* m, uint8_t msg_len) {
    start_transmit();
    jvs_sync();
    uint8_t checksum = 0;
    jvs_putc(0);
    checksum += 0;
    jvs_putc(msg_len + 2);
    checksum += msg_len + 2;
    jvs_putc(status);
    checksum += status;
    for (int i = 0; i < msg_len; i++) {
        jvs_putc(m[i]);
        checksum += m[i];
    }
    jvs_putc(checksum);
    stop_transmit();
}

uint32_t read_switches() {
    uint32_t r;
    gpio_put(PIN_SR_SH, 1);
    for (int i = 0; i < 32; i++) {
        r >>= 1;
        r |= (gpio_get(PIN_SR_DATA) ? 1 : 0) << 31;
        gpio_put(PIN_SR_CLK, 1);
        gpio_put(PIN_SR_CLK, 0);
    }
    gpio_put(PIN_SR_SH, 0);
    return ~r;
}

void update_termination() {
    if (gpio_get(PIN_JVS_SENSE_IN_HIGH)) {
        gpio_put(PIN_JVS_TERMINATION, 0);
    } else {
        gpio_put(PIN_JVS_TERMINATION, 1);
    }
}

// call periodically with switch read to check level changes of coin input
void process_coin(uint32_t switches) {
    if ((switches >> SR_C1 & 1) && !prev_coin_p1) {
        coin_count_p1++;
        if (coin_count_p1 > 16383) {
            coin_count_p1 = 16383;
        }
        meter_timeout_p1 = METER_TIMEOUT;
    }
    if ((switches >> SR_C2 & 1) && !prev_coin_p2) {
        coin_count_p2++;
        if (coin_count_p2 > 16383) {
            coin_count_p2 = 16383;
        }
        meter_timeout_p2 = METER_TIMEOUT;
    }
    prev_coin_p1 = switches >> SR_C1 & 1;
    prev_coin_p2 = switches >> SR_C2 & 1;

    if (meter_timeout_p1) meter_timeout_p1--;
    gpio_put(PIN_METER1, meter_timeout_p1 > 0);

    if (meter_timeout_p2) meter_timeout_p2--;
    gpio_put(PIN_METER2, meter_timeout_p2 > 0);

    gpio_put(PIN_LOCKOUT1, coin_count_p1 >= 16383);
    gpio_put(PIN_LOCKOUT2, coin_count_p2 >= 16383);
}

int main() {
    stdio_init_all();
    uart_init(uart0, 115200);
    uart_set_translate_crlf(uart0, false);
    gpio_set_function(0, GPIO_FUNC_UART);
    gpio_set_function(1, GPIO_FUNC_UART);
    gpio_init(PIN_JVS_RE);
    gpio_put(PIN_JVS_RE, 0); // enable receiver
    gpio_set_dir(PIN_JVS_RE, GPIO_OUT);
    gpio_init(PIN_JVS_DE);
    gpio_put(PIN_JVS_DE, 0); //disable transmitter
    gpio_set_dir(PIN_JVS_DE, GPIO_OUT);
    gpio_init(PIN_JVS_SENSE_2_5V);
    gpio_put(PIN_JVS_SENSE_2_5V, 1); // always appear present
    gpio_set_dir(PIN_JVS_SENSE_2_5V, GPIO_OUT);
    gpio_init(PIN_JVS_SENSE_0V);
    gpio_put(PIN_JVS_SENSE_0V, 0);
    gpio_set_dir(PIN_JVS_SENSE_0V, GPIO_OUT);
    gpio_init(PIN_JVS_TERMINATION);
    gpio_put(PIN_JVS_TERMINATION, 1); // disable termination by default
    gpio_set_dir(PIN_JVS_TERMINATION, GPIO_OUT);
    gpio_init(PIN_JVS_SENSE_IN_LOW);
    gpio_set_dir(PIN_JVS_SENSE_IN_LOW, GPIO_IN);
    gpio_pull_up(PIN_JVS_SENSE_IN_LOW);
    gpio_init(PIN_JVS_SENSE_IN_HIGH);
    gpio_set_dir(PIN_JVS_SENSE_IN_HIGH, GPIO_IN);
    gpio_pull_up(PIN_JVS_SENSE_IN_HIGH);

    // sr
    gpio_init(PIN_SR_DATA);
    gpio_set_dir(PIN_SR_DATA, GPIO_IN);
    gpio_init(PIN_SR_CLK);
    gpio_put(PIN_SR_CLK, 0);
    gpio_set_dir(PIN_SR_CLK, GPIO_OUT);
    gpio_init(PIN_SR_SH);
    gpio_put(PIN_SR_SH, 0);
    gpio_set_dir(PIN_SR_SH, GPIO_OUT);

    // coin/lockout drivers
    gpio_init(PIN_METER1);
    gpio_put(PIN_METER1, 0);
    gpio_set_dir(PIN_METER1, GPIO_OUT);
    gpio_init(PIN_METER2);
    gpio_put(PIN_METER2, 0);
    gpio_set_dir(PIN_METER2, GPIO_OUT);
    gpio_init(PIN_LOCKOUT1);
    gpio_put(PIN_LOCKOUT1, 0);
    gpio_set_dir(PIN_LOCKOUT1, GPIO_OUT);
    gpio_init(PIN_LOCKOUT2);
    gpio_put(PIN_LOCKOUT2, 0);
    gpio_set_dir(PIN_LOCKOUT2, GPIO_OUT);

    // ui
    gpio_init(PIN_LED_ENUMERATED);
    gpio_put(PIN_LED_ENUMERATED, 0);
    gpio_set_dir(PIN_LED_ENUMERATED, GPIO_OUT);
    gpio_init(PIN_DIP1);
    gpio_set_dir(PIN_DIP1, GPIO_IN);
    gpio_pull_up(PIN_DIP1);

    // edid emulation
    edid_init();

    update_termination();

    uint8_t prev_msg_send[JVS_OUTPUT_BUF_LEN];
    uint8_t prev_msg_size = 0;
    uint8_t prev_status = 0;

    while (true) {
        const uint64_t now = time_us_64();
        if ((now - last_process_coin) > 20000) {
            uint32_t switches = read_switches();
            process_coin(switches);
            last_process_coin = now;
        }

        if (uart_is_readable(uart0) && uart_getc(uart0) == 0xe0) {
            uint8_t our_checksum = 0;
            uint8_t node_num = jvs_getc();
            if (!((node_num == 0xff) || ((our_address == node_num) && (our_address != 0)))) {
                continue;
            }
            our_checksum += node_num;
            uint8_t length = jvs_getc();
            our_checksum += length;
            uint8_t msg_length = length - 1;
            uint8_t message[256];
            for (int i = 0; i < msg_length; i++) {
                uint8_t c = jvs_getc();
                our_checksum += c;
                message[i] = c;
            }
            uint8_t msg_send[JVS_OUTPUT_BUF_LEN];
            int o = 0;
            uint8_t status = JVS_STATUS_GOOD;
            uint8_t their_checksum = jvs_getc();
            if (our_checksum == their_checksum) {
                int i = 0;
                while (i < msg_length) {
                    if ((msg_length - i) >= 2 && message[i] == 0xf0 && message[i+1] == 0xd9) {
                        printf("N: %02x Reset\n", node_num);
                        our_address = 0;
                        gpio_put(PIN_JVS_SENSE_0V, 0);
                        gpio_put(PIN_LED_ENUMERATED, 0);
                        i += 2;
                    } else if ((msg_length - i) >= 2 && message[i] == 0xf1) {
                        uint8_t node_id = message[i+1];
                        i += 2;
                        printf("Assign node id N: %02x\n", node_id);
                        if ((our_address == 0)
                            && (gpio_get(PIN_JVS_SENSE_IN_HIGH)
                                || !gpio_get(PIN_JVS_SENSE_IN_LOW))) {
                            printf("Assigning our address\n");
                            our_address = node_id;
                            msg_send[o] = JVS_REPORT_GOOD;
                            o++;
                            gpio_put(PIN_JVS_SENSE_0V, 1);
                            gpio_put(PIN_LED_ENUMERATED, 1);
                        } else {
                            printf("We are not currently last in the chain, skipping assignment\n");
                        }
                    } else if ((msg_length - i) >= 2 && message[i] == 0xf2) {
                        uint8_t method_code = message[i+1];
                        i += 2;
                        printf("Comm. method change request: %02x\n", method_code);

                        if (method_code < (sizeof(JVS_COMM_SPEEDS)/sizeof(JVS_COMM_SPEEDS[0]))) {
                            uart_init(uart0, JVS_COMM_SPEEDS[method_code]);
                            jvs_comm_method = method_code;
                        }
                        else {
                            printf("incompatible JVS Comm. method!\n");
                        }
                        continue;
                    } else if ((msg_length - i) >= 1 && message[i] == 0x10) {
                        i++;
                        printf("Got ID code request\n");
                        msg_send[o] = JVS_REPORT_GOOD;
                        o++;
                        strcpy((char*)&msg_send[o], id_str);
                        o += strlen(id_str) + 1;
                    } else if ((msg_length - i) >= 1 && message[i] == 0x11) {
                        i++;
                        printf("Got revision request\n");
                        msg_send[o] = JVS_REPORT_GOOD;
                        o++;
                        msg_send[o] = 0x13;
                        o++;
                    } else if ((msg_length - i) >= 1 && message[i] == 0x12) {
                        i++;
                        printf("Got video revision request\n");
                        msg_send[o] = JVS_REPORT_GOOD;
                        o++;
                        msg_send[o] = 0x30;
                        o++;
                    } else if ((msg_length - i) >= 1 && message[i] == 0x13) {
                        i++;
                        printf("Got comm revision request\n");
                        msg_send[o] = JVS_REPORT_GOOD;
                        o++;
                        msg_send[o] = JVS_COMM_VER;
                        o++;
                    } else if ((msg_length - i) >= 1 && message[i] == 0x14) {
                        i++;
                        printf("Got input descriptor request\n");
                        msg_send[o] = JVS_REPORT_GOOD;
                        o++;
                        if (!gpio_get(PIN_DIP1)) {
                            memcpy(&msg_send[o], input_desc_1coin, sizeof(input_desc_1coin));
                            o += sizeof(input_desc_1coin);
                        } else {
                            memcpy(&msg_send[o], input_desc_2coin, sizeof(input_desc_2coin));
                            o += sizeof(input_desc_2coin);
                        }
                    } else if ((msg_length - i) >= 1 && message[i] == 0x15) {
                        i++;
                        printf("Got main board ID: ");
                        while (i < msg_length) {
                            char c = message[i];
                            i++;
                            if (c == 0) break;
                            putchar(message[i]);
                        }
                        printf("\n");
                        msg_send[o] = JVS_REPORT_GOOD;
                        o++;
                    } else if ((msg_length - i) >= 3 && message[i] == 0x20) {
                        int num_players = message[i+1];
                        int bytes_per_player = message[i+2];
                        i += 3;
                        if (o + num_players*bytes_per_player >= JVS_MAX_LEN) {
                            printf("JVS response overflow!\n");
                            status = JVS_STATUS_OVERFLOW;
                            break;
                        }
                        msg_send[o] = JVS_REPORT_GOOD;
                        o++;
                        uint32_t switches = read_switches();
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

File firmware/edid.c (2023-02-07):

#include "edid.h"
#include "pico/stdlib.h"
#include "i2c_slave.h"
#include "i2c_fifo.h"

#define PIN_SDA 4
#define PIN_SCL 5

static const uint8_t edid_value[128] =
    "\x00\xff\xff\xff\xff\xff\xff\x00\x31\xd8\x00\x00\x00\x00\x00\x00"
    "\x05\x21\x01\x03\x6d\x10\x0c\x78\xea\x5e\xc0\xa4\x59\x4a\x98\x25"
    "\x20\x50\x54\x00\x00\x00\x31\x40\x01\x01\x01\x01\x01\x01\x01\x01"
    "\x01\x01\x01\x01\x01\x01\x8c\x0a\x80\xda\x20\xe0\x2d\x10\x18\x60"
    "\xa4\x00\xa6\x7d\x00\x00\x00\x18\x00\x00\x00\xff\x00\x74\x64\x2d"
    "\x69\x6f\x20\x20\x20\x0a\x20\x20\x20\x20\x00\x00\x00\xfd\x00\x3b"
    "\x3d\x1e\x20\x03\x00\x0a\x20\x20\x20\x20\x20\x20\x00\x00\x00\xfc"
    "\x00\x74\x64\x2d\x69\x6f\x0a\x20\x20\x20\x20\x20\x20\x20\x00\xf6";

static int16_t edid_address = 0;

static void edid_handler(i2c_inst_t *i2c, i2c_slave_event_t event) {
    switch (event) {
        case I2C_SLAVE_RECEIVE:
            edid_address = i2c_read_byte(i2c) & 0x7F;
            break;
        case I2C_SLAVE_REQUEST:
            i2c_write_byte(i2c, edid_value[edid_address]);
            edid_address++;
            if (edid_address > 127) edid_address = 0;
            break;
        default:
            break;
    }
}

void edid_init(void) {
    gpio_init(PIN_SDA);
    gpio_init(PIN_SCL);
    gpio_pull_up(PIN_SDA);
    gpio_pull_up(PIN_SCL);
    gpio_set_function(PIN_SDA, GPIO_FUNC_I2C);
    gpio_set_function(PIN_SCL, GPIO_FUNC_I2C);

    i2c_init(i2c0, 100000);
    i2c_slave_init(i2c0, 0x50, &edid_handler);
}

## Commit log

2021-02-02 Update schematic
    [td-io.kicad_pcb, td-io.sch]
2021-02-02 Swap male to female VGA connector
    [td-io.kicad_pcb, td-io.sch]
2021-02-04 Swap audio jacks out
    [td-io.kicad_pcb, td-io.sch]
2021-02-06 Add alternative power supply
    [td-io.kicad_pcb, td-io.sch]
2021-02-07 Add JVS chaining support
    [td-io.kicad_pcb, td-io.sch]
2021-02-08 More layout fixes
    [td-io.kicad_pcb, td-io.sch]
2021-02-08 Switch from 74lv166 to 74lv165
    [td-io.sch]
2021-02-08 Add service/test/tilt
    [td-io.kicad_pcb, td-io.sch]
2021-02-08 Swap to ADA4891-3.
    [td-io.sch]
2021-02-08 Switch to class D amp
    [td-io.sch]
2021-02-10 more layout
    [td-io.kicad_pcb, td-io.sch]
2021-02-16 More PCB layout
    [td-io.kicad_pcb]
2021-02-16 update pcb
    [td-io.kicad_pcb]
2021-02-16 move stuff around a bit more
    [td-io.kicad_pcb]
2021-02-17 minor production changes
    [td-io.kicad_pcb]
2021-02-26 BOM updates
    [td-io.sch]
2021-02-28 Add todo
    [td-io.sch]
2021-03-02 Add more todos
    [td-io.sch]
2021-03-03 implement button mapping
2021-03-03 fix shift register order
    [td-io.c]
2021-03-04 Add chaining support
2021-03-04 fix meter pin mappings
    [td-io.sch]
2021-03-28 new footprints
2021-03-29 change switch
    [td-io.kicad_pcb, td-io.sch]
2021-03-29 Move some tracks around
    [td-io.kicad_pcb, td-io.sch]
2021-04-04 Add LED for enumeration status
2021-04-04 Add dip switch to toggle between 1 and 2 coin slots
2021-04-04 add dc restoration and incrase schematic size
    [td-io.kicad_pcb, td-io.sch]
2021-04-12 more fixes
    [td-io.kicad_pcb, td-io.sch]
2021-04-21 final edits
    [td-io.kicad_pcb, td-io.sch]
2021-05-04 Add JVS chaining support.
    Also fix DIP assignments.
    [td-io.c]
2021-05-04 add todos
    [td-io.sch]
2021-05-18 BOM changes
    [td-io.sch]
2021-05-27 Correct capcom chaining information
2021-12-05 changes for 1.2
    [td-io.kicad_pcb, td-io.sch]
2021-12-05 thermal opt
    [td-io.kicad_pcb]
2022-03-08 Update to KiCAD 6.0 and make some parts availability edits
    [td-io.kicad_sch, td-io.sch]
2022-03-08 drop i2c rom
    [td-io.kicad_sch]
2022-03-08 convert pcb to kicad 6
    [td-io.kicad_pcb]
2022-03-08 some pcb layout action
    [td-io.kicad_pcb, td-io.kicad_sch]
2022-03-10 finish layout
    [td-io.kicad_pcb, td-io.kicad_sch]
2022-03-11 update PCB footprints from libraries
    [td-io.kicad_pcb]
2022-03-11 update to new psu
    [td-io.kicad_pcb, td-io.kicad_sch]
2022-03-11 small fixes
    [td-io.kicad_pcb, td-io.kicad_sch]
2022-03-11 switch pca9306 to soic-8 footprint
    [td-io.kicad_pcb]
2022-03-12 add 3d models
    [td-io.kicad_pcb]
2022-03-20 re test zones
    [td-io.kicad_pcb, td-io.kicad_sch]
2023-02-05 Fix TILT magic number + typo
    [td-io.c]
2023-02-05 Limit service from being processed more often than coins. JVS' + noisy switches can cause coin problems.
    [td-io.c]
2023-02-05 Implement coin meter timeout (min/max pulse length). Fix meter pinout.
    [td-io.c]
2023-03-02 Update PCB to v1.4
    [td-io.kicad_pcb, td-io.kicad_sch]
2025-05-20 Add missing schematic sheet
    [jvs-power.kicad_sch]
